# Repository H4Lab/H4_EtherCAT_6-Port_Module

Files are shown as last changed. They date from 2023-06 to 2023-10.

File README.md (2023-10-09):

This repository replicates our internal Circuit Board Design Files repository, but only displays a portion of the material and documentation we intend to make public.
This project is  is licensed under the BSD 3-Clause "New" or "Revised" License.

H4 EtherCAT 6-port Module using Microchip LAN9254
===
# Overview
The H4 6-port EtherCAT junction enables communication between six multiple EtherCAT devices in a network. The design integrates four LAN9254 chips capable of supporting 100Mbps (100BASE-TX) operation.
It can serve as a central point in a daisy chain topology or branch topology.
With its small form factor (60x85mm), the board is designed for seamless integration into robotic solutions.
This board was specifically designed for embedded robotic applications, with the primary goal of replacing commonly available off-the-shelf modules that tend to be bulky, such as the BECKHOFF EP6228 or the OMRON GX-JC03 / JC06.  

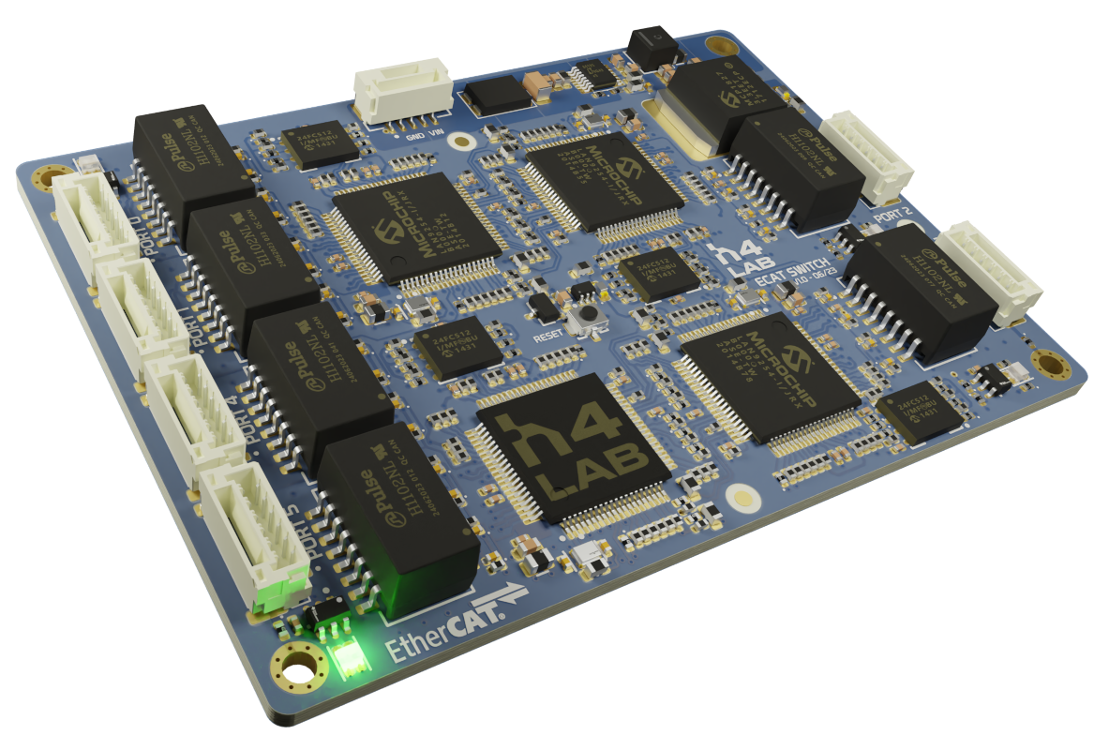
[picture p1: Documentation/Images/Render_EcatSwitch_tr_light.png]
EtherCAT Switch Rev 1.1 PCB Render


### Hardware release (production files)
* Rev 1.0 Initial version (20 August 2023)
* Rev 1.1 Ethernet ESD protection (TVS) added (15 September 2023)

### Features
* Up to 6 EtherCAT ports (JST-GH connector)
* 4x LAN9254 Slave Controller with Integrated Ethernet PHYs
* Run and Error LEDs for each slave controller
* Reset switch (also available externaly)

### Electrical specifications
* Wide Input Voltage: 6-60V (reverse polarity protected)
* Operating temperature: -40degC to +85degC (Industrial)
* Protection against electrostatic discharges (ESD) 

### Mechanical dimensions
* 60mm x 85mm (2.36" X 3.35")
* Height≈9.1mm

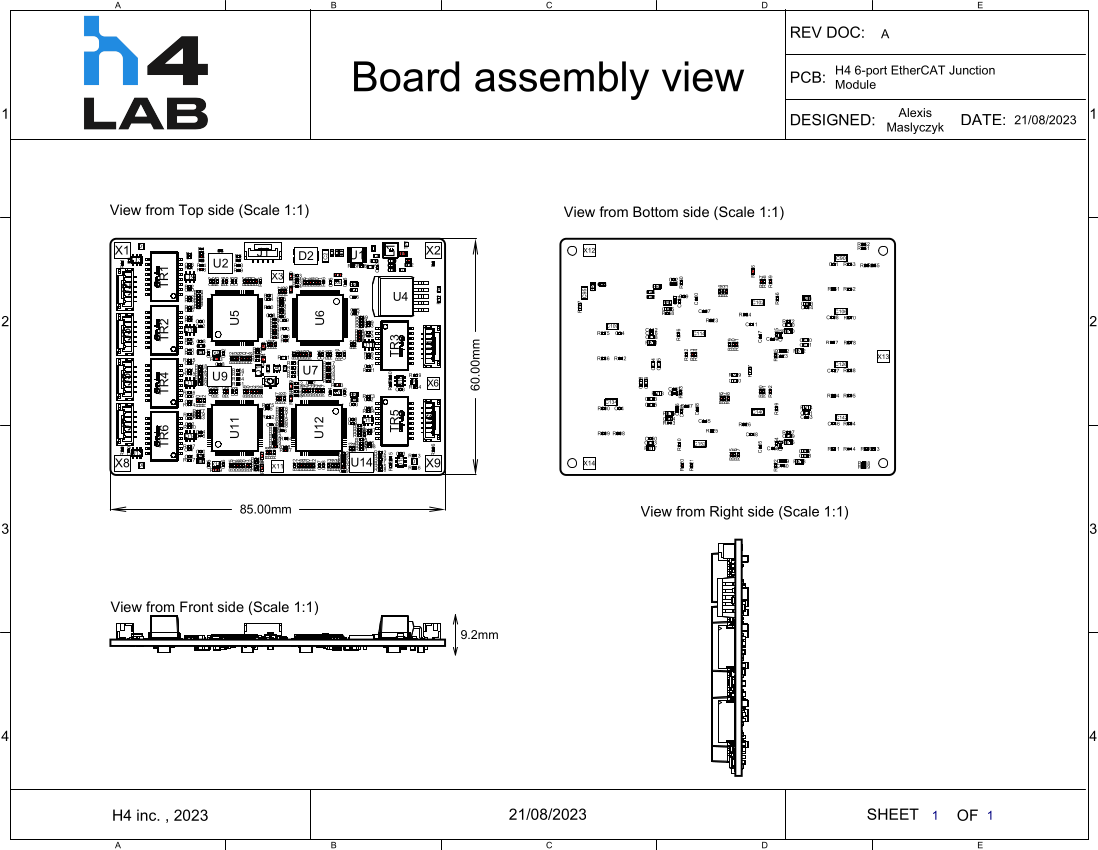
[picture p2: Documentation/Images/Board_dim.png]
Board assembled


### Files
Each board has its own folder containing the source files (schematic and layout on Altium), output files (gerber, BOM and pick and place for manufacturing), documents (schematic and layout in PDF files), images, configuration files for etherCAT etc.

### Board Assembly
Board Rev 1.1 assembled:
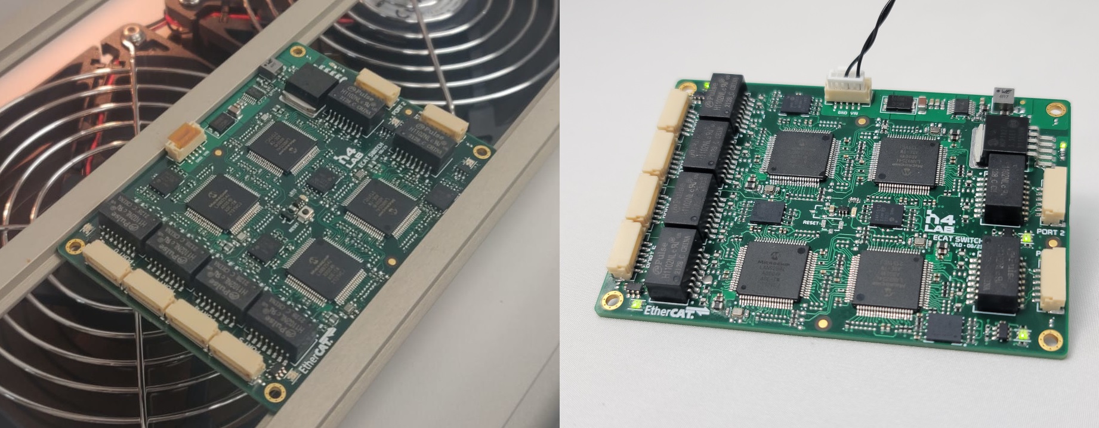
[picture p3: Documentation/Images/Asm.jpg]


### Software Configuration
The first step is to flash all the LAN EEPROM with the right configuration.
You can follow the steps provided by Microchip:
https://ww1.microchip.com/downloads/aemDocuments/documents/UNG/ProductDocuments/SupportingCollateral/6-Port-EtherCAT-Coupler-EVB-LAN9254-DIGIO-50003263.pdf

ETHERCAT DEVICE
1. Connect the boards and power on the boards.
2. Connect the Port 0 (Board 1) to the PC running TwinCAT using the Ethernet cable.
3. Download the configuration file (ESI) from the product page and copy the LAN9254-EtherCAT-Junction-Box configuration file to TwinCAT directory TwinCAT\3.1\Config\Io\EtherCAT.
4. Once the new project is created, in the Project Solution pane, expand the I/O section and right-click Devices. Click Scan to scan the EVBs.
5. After scanning the device, the dialog box may appear. Click OK in the dialog box if it appears.
6. Check if the window appears with your Device check box ticked. This is an indication that the Ethernet cable is properly connected to the board and the PC. Click OK.
7. Click Yes when prompted with “Scan for boxes” in a dialog box
8. The Activate Free Run dialog box appears. Click Yes to Activate Free Run.
9. In the Solution Explorer pane, find and click your Device (EtherCAT). The TwinCAT Test_EtherCAT Coupler tab appears. Four boxes should be present in the Online tab, as there are four ESCs. The ESCs are not in “OP” state because the EEPROM has to be updated with the respective configuration file.
10. Select and right click Box 1 (ESC 1). Click EEPROM Update and then OK toload the new configuration into the EEPROM.
11. In the Write EEPROM dialog box, the LAN9254-EtherCAT-Junction-Box configuration file can be found.
Note: Make sure step 3 is completed, otherwise the configuration file cannot be found.
12. Select the Show Hidden Devices check box in the Write EEPROM dialog box. As Box 1 (ESC 1) is selected in step 10, select Microchip-LAN9254- EtherCAT-Junction-Box, and click OK.
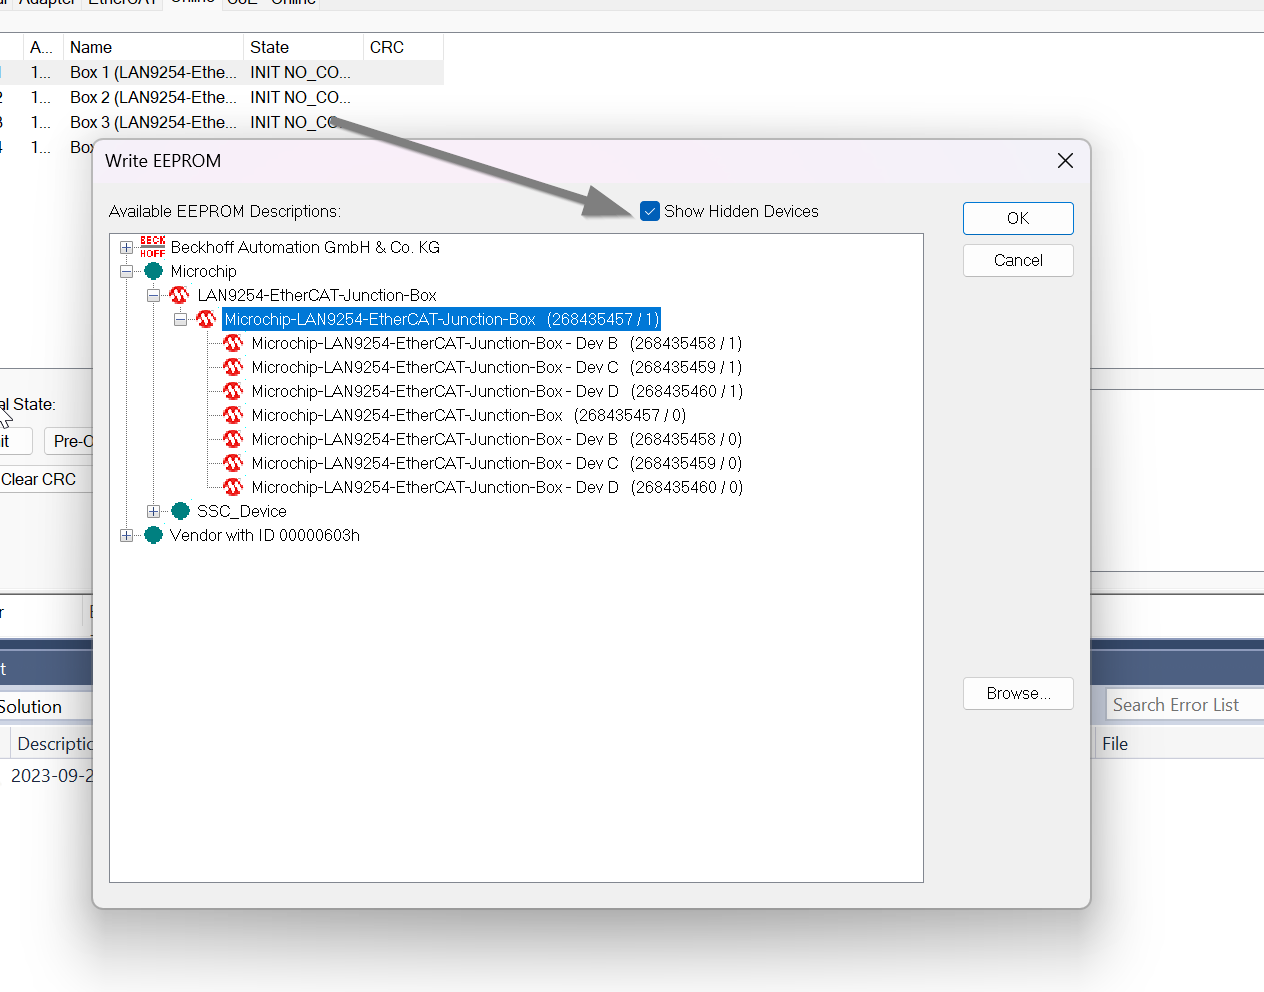
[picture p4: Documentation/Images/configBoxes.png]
EEPROM Config Boxes

13. Repeat steps 10 to 12 for Devices 2, 3, and 4 but selecting the following:
Device 2 Box 2 (ESC 2) Microchip-LAN9254-EtherCAT-Junction-Box-Dev-B
Device 3 Box 3 (ESC 3) Microchip-LAN9254-EtherCAT-Junction-Box-Dev-C
Device 4 Box 4 (ESC 4) Microchip-LAN9254-EtherCAT-Junction-Box-Dev-D
14. After loading all the EEPROMs with respective configuration files, rescan the device. Right-click Device 3 (EtherCAT) and click Scan.
15. Once the above steps are done correctly, all the devices states should read as “OP”.
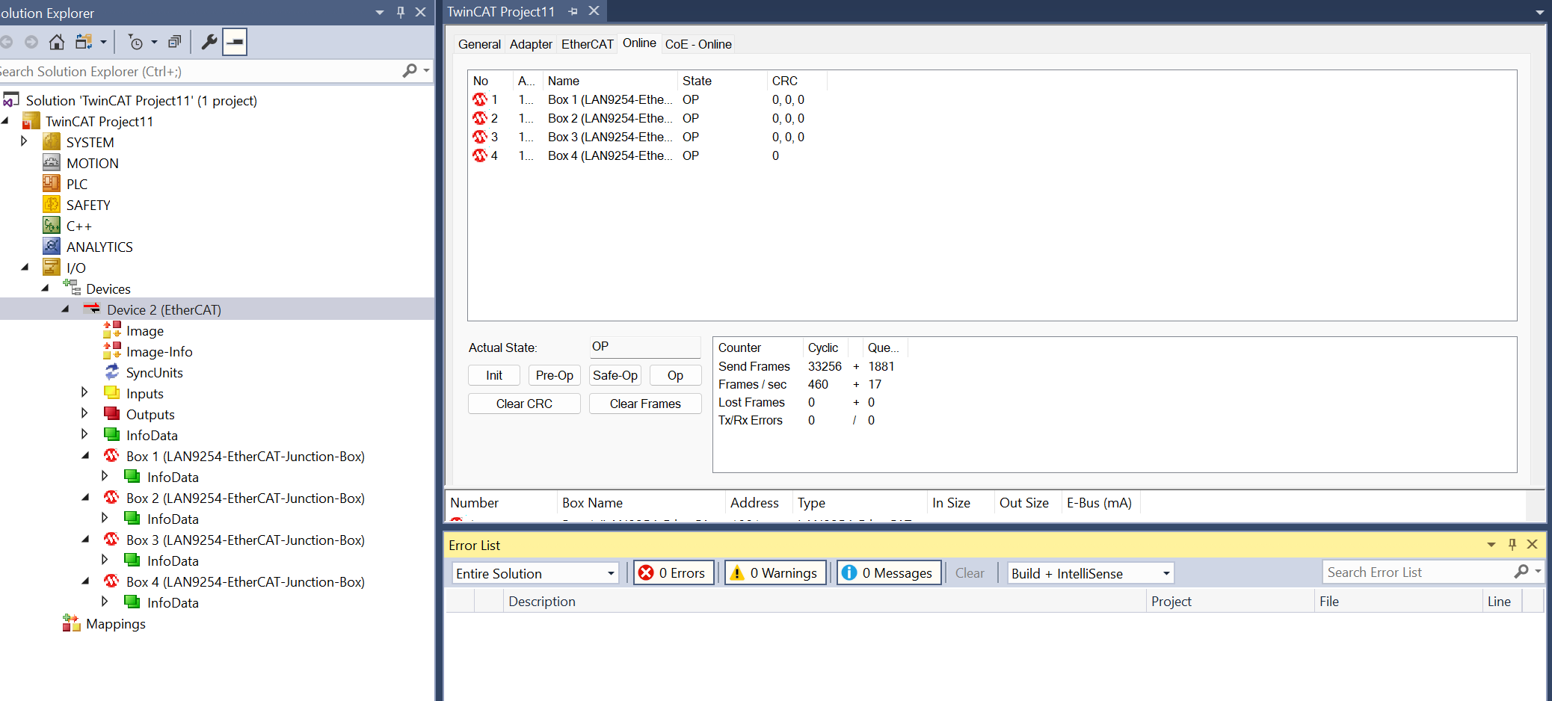
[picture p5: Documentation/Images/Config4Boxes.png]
OP


### EtherCAT Slave testing
1. Connect one EtherCAT slave to one port of the boards and power on the boards.
2. After scanning the device, the dialog box may appear. Click OK in the dialog box if it appears.
3. The Activate Free Run dialog box appears. Click Yes to Activate Free Run.
4. You should now see your EtherCAT slave connected:
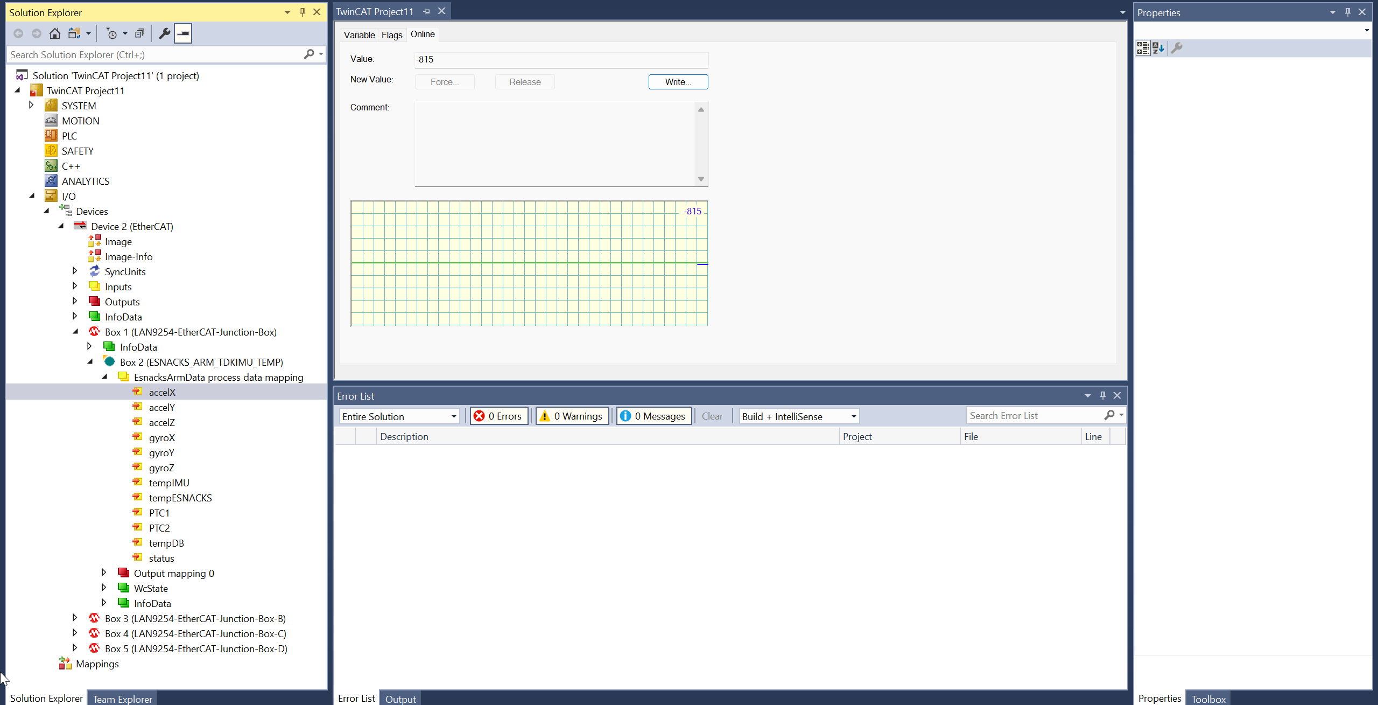
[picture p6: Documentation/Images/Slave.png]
EtherCAT Slave


The board underwent comprehensive testing and functioned as anticipated within the specified wide input voltage range. All EtherCAT ports were individually tested with a variety of EtherCAT slaves, including the TI F28388, LAN9252, and Beckhoff ET1100, among others.
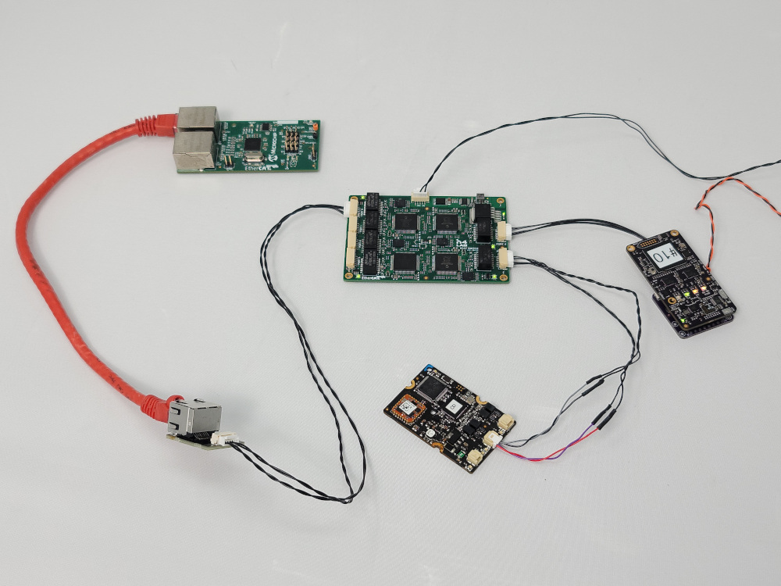
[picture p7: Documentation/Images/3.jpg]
Multi EtherCAT slaves connected


NOTE: We don't have the setup and equipment to test the ESD protections. We selected the transient protection diode for Ethernet with the parameters listed:
* Working voltage at least to be 3.3V.
* Clamping voltage at 1A Ipp parameter has to be within absolute maximum voltage rating limit (5V)
* Capacitance parameter to be < 5pF loading.
* Leakage current to be < 1 μA.
For more detailed information please refer the following Transient protection App note in the below link
http://ww1.microchip.com/downloads/en/AppNotes/00002157B.pdf

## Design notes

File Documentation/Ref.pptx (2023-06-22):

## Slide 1

Top sig
GND
Horizontal Sig
Vertical Sig
PWR
Bot sig

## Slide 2

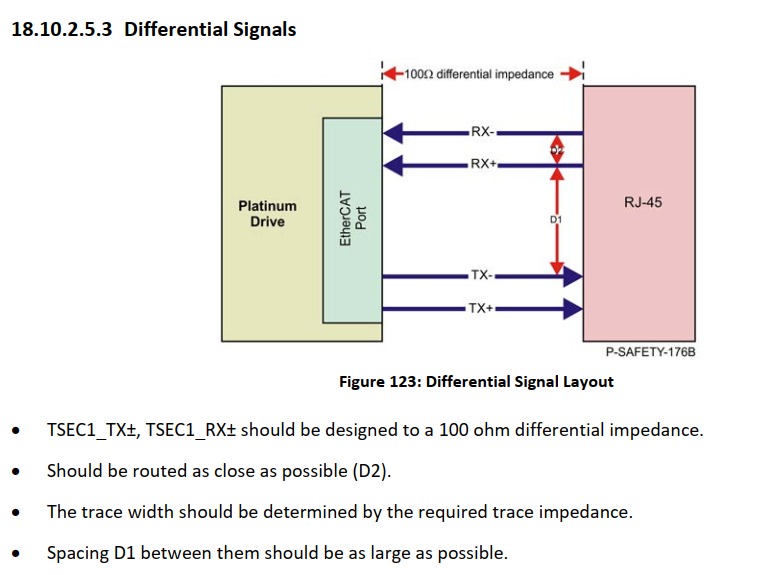
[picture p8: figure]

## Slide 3

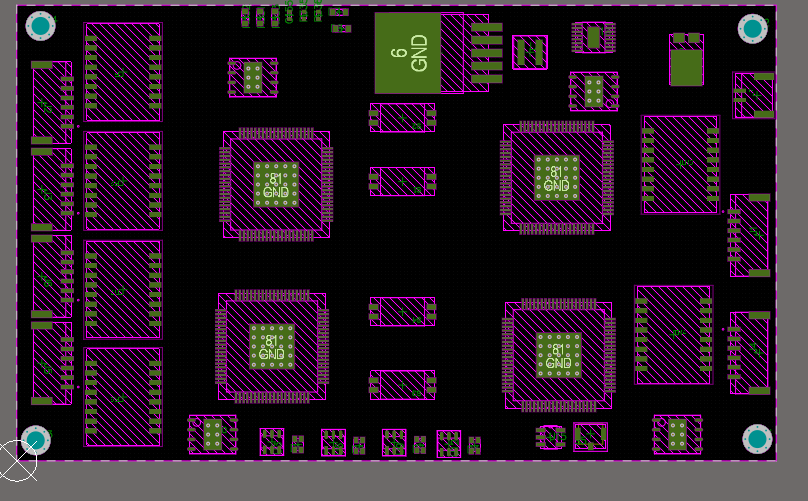
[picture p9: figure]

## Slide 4

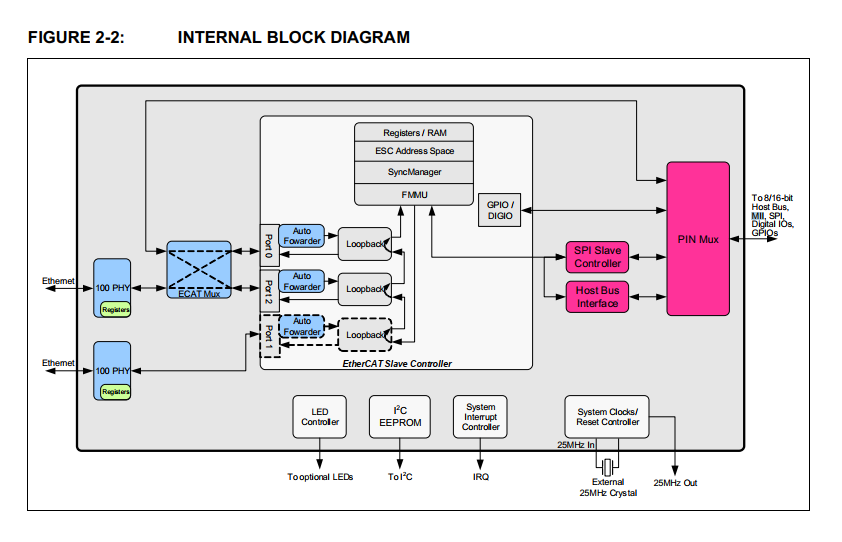
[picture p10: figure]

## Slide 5

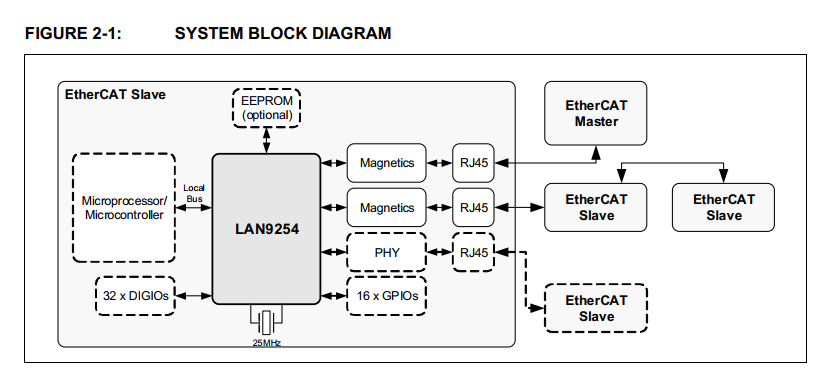
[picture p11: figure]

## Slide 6

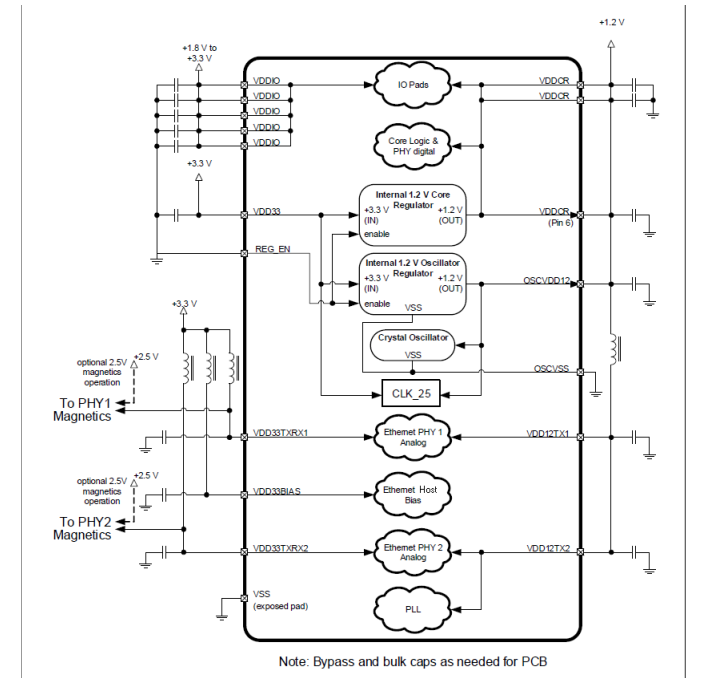
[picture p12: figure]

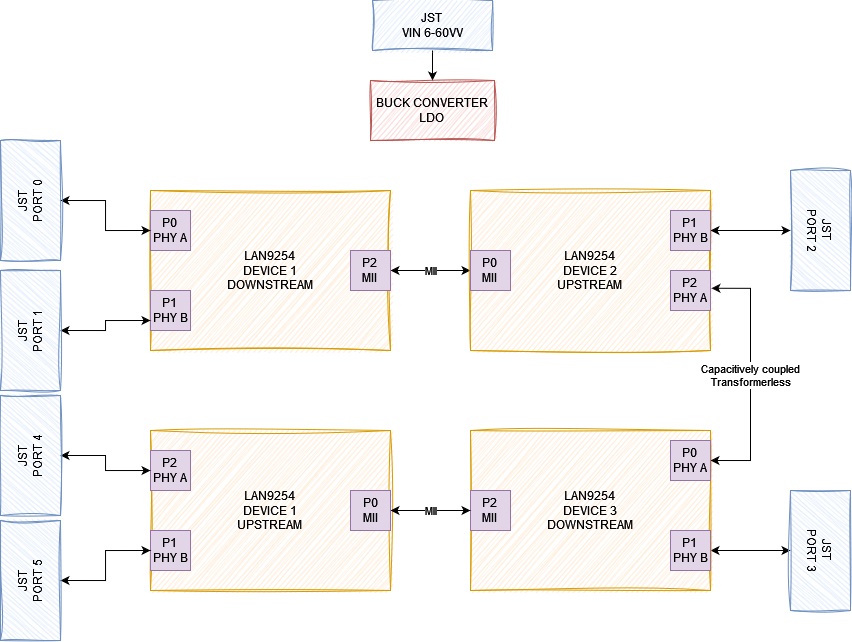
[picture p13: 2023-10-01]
Documentation/Images/Diagram.jpg

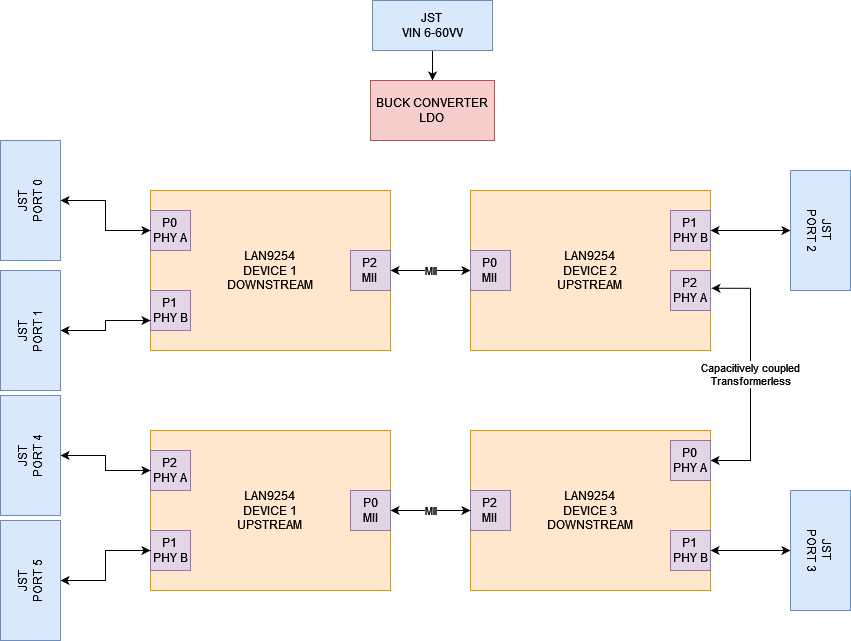
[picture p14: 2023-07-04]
Diagramme.drawio.png

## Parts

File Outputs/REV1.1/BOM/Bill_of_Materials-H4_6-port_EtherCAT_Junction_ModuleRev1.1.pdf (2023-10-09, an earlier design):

Part Number | Device | Description | Value | Package | QTY
U1 | LT8619IMSE#PBF | LT8619 - 60V, 1.2A Synchronous Monolithic Buck Regulator with 6µA Quiescent Current | SOP50P490X110-17N | 1
U2, U7, U9, U14 | 24FC512-I/MF | EEPROM Serial-2Wire 512K-bit 64K x 8 1.8V/2.5V/3.3V/5V 8-Pin DFN-S EP Tube | DFNS-MF8 | 4
U3, U10, U13, U15 | SN74LVC2G06DBVR | Buffer/Driver 2-CH Inverting Open Drain CMOS 6-Pin SOT-23 T/R | FP-DBV0006A-IPC_C | 4
U4 | MCP1827-3302E/ET | MCP1827-3302E/ET; LDOVoltage Regulator; 1.5A; 3.3V +/-2%; 2.3 to 6Vin; 5-Pin D2PAK | 5-DDPAK _Model2 | 1
U5, U6, U11, U12 | LAN9254-I/JRX | 2/3-PORT Ethercat Slave Controller With 32 Digios With Integrated Ethernet Phys | QFP50P1400X1400X120-81N | 4
U8 | 74AHC1G14GW,125 | 74AHC1G14GW/UMT5/REELR// | NXP-SOT353-1_L_TSSOP5 | 1
X4, X5, X7, X10 | XRCGB25M000F3A00R0

Crystal 25MHz ±30ppm (Tol) ±35ppm (Stability) 6pF 100Ohm Automotive 4-Pin SMD T/R

FP-XRCGB-MFG | 4
Q1 | 2N7002A-7 | MOSFET N-CH 60V 0.18A SOT23 | SOT95P230X110-3N | 1
D1, D6, D7, D8 | LTST-C195KGJRKT | LED GREEN/RED CLEAR CHIP SMD | Dual_LED | 4
D2 | MBR10U150-TP | Diode Schottky 150V 10A TO277 | TO-277 | 1
D3, D4 | LTST-C193KGKT-5A | LED GREEN CLEAR CHIP SMD | LEDC1608X07N(0603) | 2
D9, D10, D11, D12, D13, D14 | TVS3V3L4UE6327HTSA1 | Trans Voltage Suppressor Diode, 3.3V V(RWM), Unidirectional, 4 Element, Silicon | FP-SOT457-MFG | 6
D5 | LTST-C193KRKT-5A | LED RED CLEAR CHIP SMD | LEDC1608X07N(0603) | 1
J1 | BM05B-GHS-TBT | GH Series 5 Circuits 1.25 mm Pitch Disconnectable Top Entry Shrouned Header | FP-BM05B-GHS-TBT_LF_SN-MFG | 1
J2, J3, J4, J5, J6, J7 | BM06B-GHS-TBT | CONN HEADER GH TOP 6POS 1.25MM | JST_GH_6POS_STRAI | 6
S1 | B3U-1100P | Switch Tactile N.O. SPST Round Button Gull Wing 0.05A 12VDC 1.5N SMD Embossed T/R | FP-B3U-1100P-MFSWITCH_G | 1

CONNECTOR & SWITCHES

# Bill of Materials – H4 EtherCAT 6-Port Module - REV 1.0

IC

MOSFET, IGBT, BJT

DIODE

XTAL & OSCILLATORS

Updated on 2023-10-08 | Page 1/4

Part Number | Device | Description | Value | Package | QTY

# Bill of Materials – H4 EtherCAT 6-Port Module - REV 1.0

C1, C3, C4, C50, C105, C110, C124, C125, C128, C129, C130, C144, C149 | CL10B104KC8NNNC | CAP CER 0.1UF 100V X7R 0603 | 0.1uF | CAPC1608X09N(0603) | 13
C2 | C3216X7S2A225K160AB | CAP CER 2.2UF 100V X7S 1206 | 2.2uF | CAPC3216X16N(1206) | 1
C5, C8, C17, C18, C19, C23, C24, C25, C27, C28, C30, C32, C36, C38, C44, C45, C46, C48, C52, C53, C57, C58, C59, C63, C65, C68, C69, C70, C73, C74, C75, C78, C79, C80, C82, C83, C87, C88, C89, C92, C99, C100, C101, C104, C107, C111, C112, C115, C116, C117, C119, C137, C138, C139, C143, C145, C147, C148, C150, C154, C155, C156 | GRM155R71C104JA88D | CAP CER 0.1UF 16V X7R 0402 | 100nF | CAPC1005X03N(0402) | 62
C6, C11, C21, C39, C60, C84, C96, C98, C103, C118, C120, C121, C133, C135, C141, C153, C157, C158 | C0603C105K3PACTU | MLCC - SMD/SMT 25volts 1uF X5R 10% | 1uF | CAPC1608X09N(0603) | 18
C7, C13, C20, C22, C26, C31, C33, C35, C37, C40, C43, C47, C49, C51, C56, C61, C62, C66, C67, C71, C72, C76, C77, C81 | C0402C100J5GAC7411 | Cap Ceramic 10pF 50V C0G 5% SMD 0402 125°C Punched Paper T/R | 10pF | 0402_C | 24
C10 | C1608X5R1A226M080AC | CAP CER 22UF 10V X5R 0603 | 22uF | CAPC1608X09N(0603) | 1
C14 | CL10A475KP8NNNC | CAP CER 4.7UF 10V X5R 0603 | 4.7uF | CAPC1608X09N(0603) | 1
C15, C16, C41, C42, C54, C55, C85, C86 | GRM0225C1H130GA03L | Cap Ceramic Monolithic 13pF 50VDC 2% SMD Emboss T/R | 13pF | 0402_C | 8
C29, C123, C131, C160 | GCM1555C1H471JA16D | CAP CER 470PF 50V C0G/NP0 0402 | 470pF | CAPC1005X03N(0402) | 4
C34, C64, C91, C108, C127, C146 | GCM155R71H223KA55D | CAP CER 0.022UF 50V X7R 0402 | 22nF | CAPC1005X03N(0402) | 6
C90, C106, C109, C126, C134, C142 | CC1206KKX7RDBB102 | CAP CER 1000PF 2KV X7R 1206 | 1nF | CAPC3216X16N(1206) | 6
C93, C97, C113, C122, C132, C136, C151, C159 | LMK107BJ105KA-T | Multilayer Ceramic Capacitors (High dielectric type), 10V, 1 uF, ± 10 %, 0603, X5R, RoHS | 1uF | 0603_C | 8
C94 | GRM188R61A225KE34D | CAP CER 2.2UF 10V X5R 0603 | 2.2uF | CAPC1608X09N(0603) | 1
C95 | GRM319R6YA106KA12D | MLCC - SMD/SMT 1206 10uF 35volts | 10uF | CAPC3216X16N(1206) | 1
C102, C114, C140, C152 | CL31B475KBHNNNE | CAP CER 4.7UF 50V X7R 1206 | 4.7uF | CAPC3216X16N(1206) | 4

CAPACITOR

Updated on 2023-10-08 | Page 2/4

Part Number | Device | Description | Value | Package | QTY

# Bill of Materials – H4 EtherCAT 6-Port Module - REV 1.0

R2, R17 | RC0603FR-071ML | RES SMD 1M OHM 1% 1/10W 0603 | 1M | RESC1608X09N(0603) | 2
R3, R7, R9, R14, R117, R122, R123, R125, R127, R132, R133, R140, R214, R221, R226, R248 | CRGCQ0402F100R | Res Thick Film 0402 100 Ohm 1% 0.063W(1/16W) ±200ppm/C Pad SMD Automotive T/R | 100R | 0402 | 16
R4, R21, R42, R53, R63, R69, R71, R77, R83, R89, R90, R115, R121, R135, R146, R173, R174, R180, R184, R187, R190, R197, R198, R217, R269, R271, R273, R274, R301, R302, R305, R306 | CRCW040249R9FKED | RES SMD 49.9 OHM 1% 1/16W 0402 | 49.9 | RESC1005X06N(0402) | 32
R8, R11, R25, R26, R91, R102, R112, R147, R148, R205, R206, R222, R225, R261, R277, R294, R308, R311 | RCS04020000Z0ED | VISHAY - RCS04020000Z0ED - SMD Chip Resistor, 0402 [1005 Metric], 0 ohm, RCS Series, 50 V, Thick Film, 200 mW | 0R | 0402 | 18
R10 | RC0603JR-070RL | RES SMD 0 OHM JUMPER 1/10W 0603 | 0R | RESC1608X09N(0603) | 1
R12, R52 | RC0603FR-07680RL | RES SMD 680 OHM 1% 1/10W 0603 | 680R | RESC1608X09N(0603) | 2
R13, R19, R116, R120, R134, R141, R216, R220 | CRCW04022K20JNED | Vishay CRCW Series Thick Film Resistor 0402 Case 2.2k 5% 0.063W 200ppm/K | 2k2 | 0402 | 8
R15 | ERJ-2RKF2002X | RES SMD 20K OHM 1% 1/10W 0402 | 20k | 0402 | 1
R16 | ERJ-2RKF1913X | Thick Film Resistors - SMD 0402 191Kohms 1% Tol | 191k | 0402 | 1
R23, R32, R34, R43, R49, R50, R59, R60, R73, R80, R82, R92, R99, R101, R114, R142, R155, R157, R164, R171, R172, R181, R182, R194, R203, R204, R224, R234, R236, R250, R260, R266, R276, R285, R293, R299, R310, R322 | RC0402FR-0710KL | RES SMD 10K OHM 1% 1/16W 0402 | 10k | RESC1005X06N(0402) | 38
R24, R44, R57, R62, R65, R66, R70, R76, R88, R103, R145, R165, R178, R185, R188, R189, R192, R199, R218, R244, R323, R324, R325, R326 | CRGP0402F22R | Res Thick Film 0402 22 Ohm 1% 0.125W(1/8W) ±200ppm/C Pad SMD T/R | 22R | 0402 | 24
R33, R100, R156, R235 | RC0402FR-074K75L | RES SMD 4.75K OHM 1% 1/16W 0402 | 4k75 | RESC1005X06N(0402) | 4

RESISTOR

Updated on 2023-10-08 | Page 3/4

Part Number | Device | Description | Value | Package | QTY

# Bill of Materials – H4 EtherCAT 6-Port Module - REV 1.0

R111 | RC0603FR-072K2L | RES SMD 2.2K OHM 1% 1/10W 0603 | 2k2 | RESC1608X09N(0603) | 1
R129, R144, R213, R246, R251, R252, R318, R319 | CRCW0402470RJNED | Vishay CRCW Series Thick Film Resistor 0402 Case 470 5% 0.063W 200ppm/K | 470 | 0402 | 8
R130, R138, R215, R223, R254, R255, R312, R313 | CRCW04021M50JNED | RES SMD 1.5M OHM 5% 1/16W 0402 | 1M5 | 0402 | 8
R253, R262, R270, R275, R278, R286, R288, R295, R300, R304, R309, R314 | CRCW040275R0FKEDC | RES SMD 75 OHM 1% 1/16W 0402 | 75R | RESC1005X06N(0402) | 12
R267 | CRCW06031K00FKEA | MD 1/10watt 1.0Kohms 1% | 1k | RESC1608X09N(0603) | 1
R268, R272, R303, R307 | RC0402FR-0712K1L | RES SMD 12.1K OHM 1% 1/16W 0402 | 12k1 | RESC1005X06N(0402) | 4
R287 | RC0603FR-073KL | RES SMD 3K OHM 1% 1/10W 0603 | 3k | RESC1608X09N(0603) | 1
R289 | RT0603BRB0710KL | RES SMD 10K OHM 0.1% 1/10W 0603 | 10k | 0603 | 1
FB2, FB3, FB4, FB5, FB6, FB7, FB8, FB9, FB10, FB11, FB12, FB13, FB14, FB15, FB16, FB17, FB18 | BKP2125HS600-T | TAIYO YUDEN - BKP2125HS600-T - Ferrite Bead, 0805 [2012 Metric], 60 ohm, 3 A, BKP Series, 0.025 ohm, ± 25% | | FP-BKP2125-IPC_C | 17
TR1, TR2, TR3, TR4, TR5, TR6 | H1102NL | Telecom Transformer 1:1/1:1 16Term. Gull Wing SMD | | FP-H1102NL-MODEL2 | 6
L1 | XGL4030-472MEC | Inductor Power Shielded Wirewound 4.7uH 20% 1MHz Composite 6.6A 31.5mOhm DCR Automotive T/R | 4u7 | FP-XGL4030-472MEC-MFG | 1

407

INDUCTOR, TRANSFORMERS & FERRITE BEADS

### Total number of components

Updated on 2023-10-08 | Page 4/4

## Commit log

2023-05-08 Add files via upload
    First commit
    [BlockDiagram.SchDoc, ECAT SWITCH.SchDoc, H4_6-port_EtherCAT_Junction_Module.PrjPcb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]
2023-05-12 Successful Compilation of Initial Board Design
    Ensured project compiles without errors, defined preliminary board outline dimensions and placed core components on the board.
    [H4_6-port_EtherCAT_Junction_Module.PrjPcb, Overview.SchDoc, Power.SchDoc]
2023-06-22 Preliminary routing of LAN IC A
    - Removed duplicate pull-up resistors on the MII interface between LAN ICs A and B (on pages 5 and 7)
    - Centralized pull-up resistors on the MII interface signals to page 3 (ECAT SWITCH) to improve readability
    - Removed switches used to configure TX shift timings for LAN ICs A and B
    - Tentative routing and component placements for LAN IC A
    - Reduced board length from 100mm to 85mm
    - Added the project integrated library (H4_6-port_EtherCAT_Junction_Module) to git
    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
    [ECAT SWITCH.SchDoc, H4_6-port_EtherCAT_Junction_Module.PcbLib, H4_6-port_EtherCAT_Junction_Module.PrjPcb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]
2023-06-22 Update Overview.SchDoc
    Test commit push
    [Overview.SchDoc]
2023-06-23 Rerouting LAN A and B's MII Interface
    Changed the MII interface's pull-up and series resistors position to avoid vias and
    [H4_6-port_EtherCAT_Junction_Module.PrjPcb, LAN9254_A_P1.SchDoc, LAN9254_B_P1.SchDoc]
2023-06-24 Preliminary placement of all components
    - Removed duplicate pull-up resistors on the MII interface between LAN ICs C and D (on pages 9 and 11)
    - Centralized pull-up resistors on the MII interface signals for LAN IC C&D to page 3 (ECAT SWITCH) to improve readability
    - Removed switches used to configure TX shift timings for LAN ICs C and D
    - Tentative placement for all components except fiducials and ferrite beads
    - Tentative routing of core signals, i.e. MII and differential pair "magnetic" signals
    - Reassigned differential pair signals on connector J4,J5 and J6 to the pin assignment of J2 and J3
    [BlockDiagram.SchDoc, ECAT SWITCH.SchDoc, H4_6-port_EtherCAT_Junction_Module.PrjPcb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]
2023-06-24 Decoupling capacitor placement and routing LAN A
    [LAN9254_A_P1.SchDoc, LAN9254_B_P1.SchDoc, LAN9254_C_P1.SchDoc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]
2023-06-24 Decoupling capacitor placement and routing LAN D
    [H4_6-port_EtherCAT_Junction_Module.PrjPcb]
2023-06-25 Decoupling capacitor placement LAN B and C
    [LAN9254_A_P1.SchDoc, LAN9254_B_P1.SchDoc, LAN9254_C_P1.SchDoc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]
2023-06-26 Routing done on all 4 LAN ICs
    [ECAT SWITCH.SchDoc, LAN9254_A_P1.SchDoc, LAN9254_B_P1.SchDoc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]
2023-06-26 Step et connecteurs
    Changement des STEP models
    Changement connecteur VIN 5pin + reset
    [LAN9254_A_P1.SchDoc, LAN9254_B_P1.SchDoc, LAN9254_C_P1.SchDoc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]
2023-06-27 Complete Routing minus GND
    [LAN9254_B_P1.SchDoc, LAN9254_D_P1.SchDoc, Power.SchDoc]
2023-06-28 Completed Layout
    - Layout fully completed (no unconnected nets)
    - Changed rectangular pads to rounded rectangular pads
    - X11, X12, X13 and X14 are causing Hole to Hole clearance issues
    - No DRC issues otherwise
2023-07-01 Completed Overlay
    [H4_6-port_EtherCAT_Junction_Module.PrjPcb, LAN9254_A_P1.SchDoc, LAN9254_B_P1.SchDoc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]
2023-07-04 Variant 1.0
    Variant 1.0 with NOT FITTED components
    Verif connections
    [ECAT SWITCH.SchDoc, H4_6-port_EtherCAT_Junction_Module.PrjPcb, LAN9254_B_P2.SchDoc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]
2023-07-04 Template update
    Template update
    [BlockDiagram.SchDoc, ECAT SWITCH.SchDoc, H4_6-port_EtherCAT_Junction_Module.PrjPcb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]
2023-07-04 Re-Annotate fait
    Re-Annotate fait
    No Differences betweeen Sch and Layout
    Compile OK
    DRC OK
    [ECAT SWITCH.SchDoc, H4_6-port_EtherCAT_Junction_Module.PrjPcb, LAN9254_A_P1.SchDoc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]
2023-07-04 Teardrop Done +Output Job
    Teardrop Done +Output Job
    [BlockDiagram.SchDoc, H4_6-port_EtherCAT_Junction_Module.PrjPcb, Overview.SchDoc]
2023-07-04 Corrections PDF
    Corrections PDF
    [Bill of Materials-H4_6-port_EtherCAT_Junction_Module(Rev1.0).xlsx, BlockDiagram.SchDoc, ECAT SWITCH.SchDoc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]
2023-07-14 Ajout schema TVS, transfo industrial et 22R
    [ECAT SWITCH.SchDoc, H4_6-port_EtherCAT_Junction_Module.PrjPcb, LAN9254_A_P1.SchDoc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]
2023-07-16 Completed Layout with TVS
    [LAN9254_A_P1.SchDoc, LAN9254_B_P1.SchDoc, LAN9254_C_P1.SchDoc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]
2023-08-07 Revised layout with TVS
    [H4_6-port_EtherCAT_Junction_Module.PrjPcb, LAN9254_A_P1.SchDoc, LAN9254_B_P1.SchDoc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]
2023-10-01 Board asm images added
2023-10-09 Rev 1.1 release
    [Bill_of_Materials-H4_6-port_EtherCAT_Junction_ModuleRev1.1.xlsx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]
2024-03-06 Rev 1.2 - Added via under DC/DC GND pad
    [H4_6-port_EtherCAT_Junction_Module.PrjPcb]
2024-03-07 Release V1.2 ( Vias in power pad U1 and silkscreen update)
    [BlockDiagram.SchDoc, ECAT SWITCH.SchDoc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]
